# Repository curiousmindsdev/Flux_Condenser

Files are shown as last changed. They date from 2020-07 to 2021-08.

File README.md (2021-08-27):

# Flux Condenser Rev.3

### What is it?

A tiny (35mm x 25mm) PCB badge featuring 24 LEDs that animate to create the “fluxxing” effect. It’s 100% decorative, it doesn’t actually let you travel through time when worn around the neck.

It is controlled by a Microchip ATtiny816 microcontroller. Thankfully this board has a much lower power requirement than the silkscreen indicates on the back, and skips along, sipping power from the single CR2032/LIR2032 coin cell battery (instead of plutonium or a lightning strike), slipped into the rear mounted coin cell holder.

https://user-images.githubusercontent.com/56890227/131141057-b0eb6197-e710-4d84-89a1-9ab057af56d6.mov

https://user-images.githubusercontent.com/56890227/131141300-c1670cdc-f619-4a5a-8890-5401563677f6.mov

### What is changed from Rev.2 to Rev.3?

Thanks to Microchip’s latest ATtiny816 microcontroller now I can dim the LEDs with 8 individual PWM pins. Users can now change the animation type, animation speed, and LED brightness. There are 2 animation types (multi beam and single beam), 2 animation speeds (slow and fast), 4 LED brightness levels (100%, 75%, 50% and 25%).  Power consumption is drastically lowered. At full brightness it draws 2.3mA and at 25% brightness it draws 1.1mA of current from the battery. Also front of the Flux Condenser is now much cleaner. Most of the via drill holes are gone.

### How long will the battery last?

CR2032 (Non-Rechargeable) with average of 210mAh battery capacity.
-	100% LED Brightness :   91 Hours
-	25% LED Brightness	 :   190 Hours

LIR2032 (Rechargeable) with average of 40mAh battery capacity.
-	100% LED Brightness :   17 Hours
-	25% LED Brightness	 :   36 Hours

### Configuration 

To set your desired animation, speed and LED brightness, you have to start flux condenser with configuration interface. In order to do that, you have to turn off your flux condenser. While holding the “Start” button on the back turn the flux condenser on. Now you should see configuration interface. Some of the LEDs should be on and some off according to your configuration. LEDs on each row of all columns, starting from outer to inner are paralleled.  
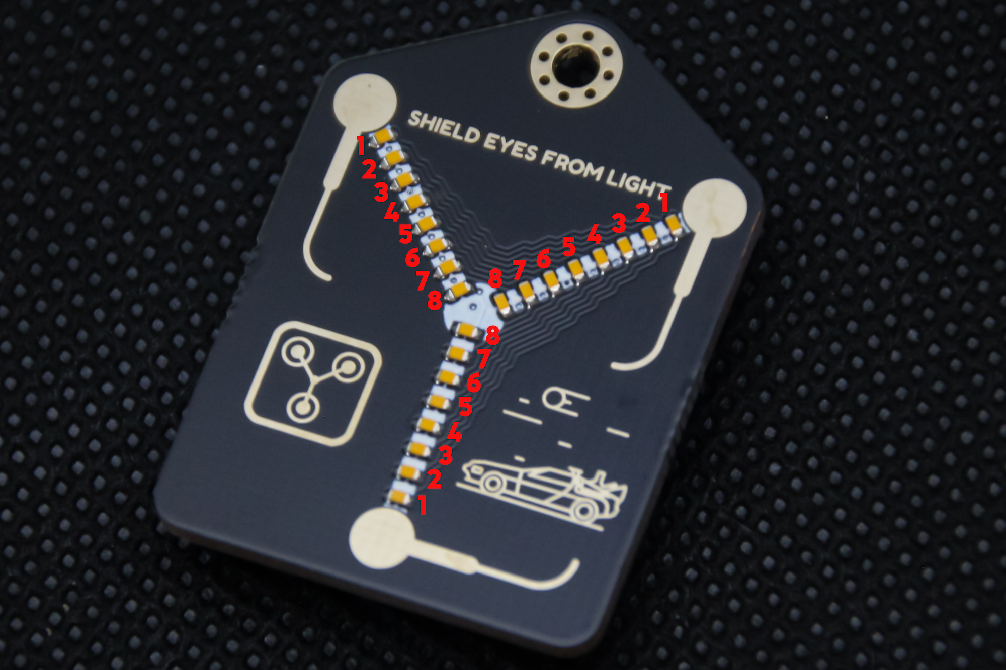
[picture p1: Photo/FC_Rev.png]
LED Numbers

Each LED number from photo shown above represents different setting.

- LED1 : Single Beam Animation
- LED2 : Multi Beam Animation
- LED3 : Slow Animation Speed
- LED4 : Fast Animation Speed
- LED5 : 100% LED Brightness
- LED6 : 75% LED Brightness
- LED7 : 50% LED Brightness
- LED8 : 25% LED Brightness

To choose your preference just hold the start button. All the LEDs should turn off and after a second starting from LED1 each individual LED gets lit. Hold the start until the LED that represents your preferred setting is lit, then release the button. Now your new configuration is set. To see it in more detail check out the video below.

https://www.youtube.com/watch?v=2X2gqoI-mSA

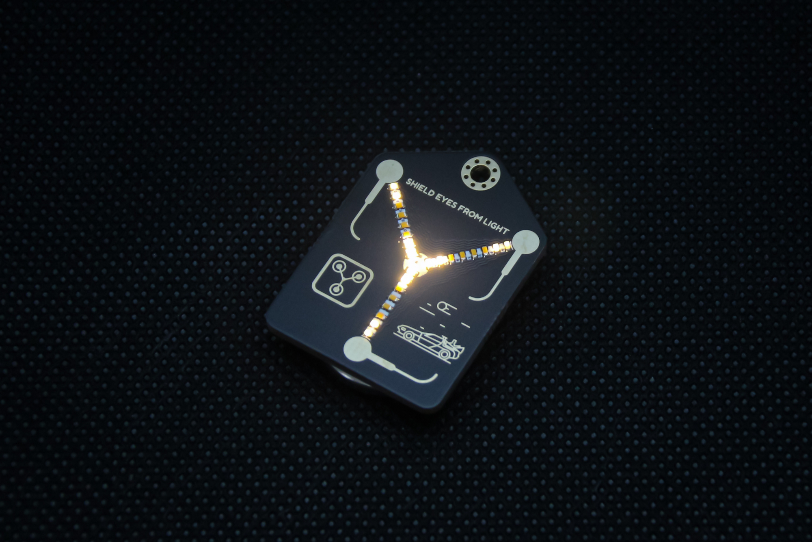
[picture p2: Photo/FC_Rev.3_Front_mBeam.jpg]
Multi Beam

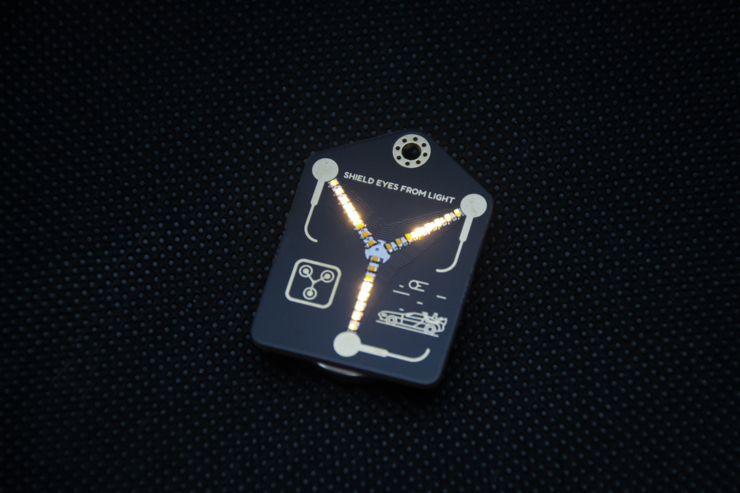
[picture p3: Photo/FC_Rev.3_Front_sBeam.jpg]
Single Beam

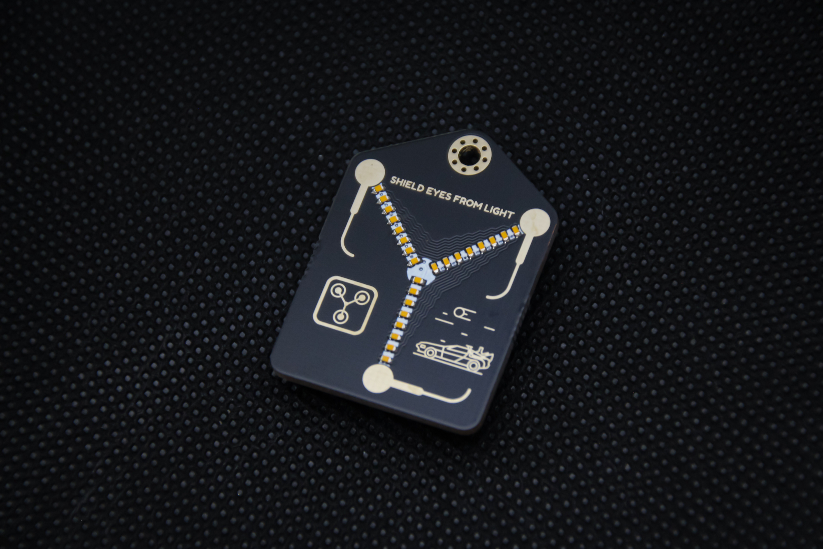
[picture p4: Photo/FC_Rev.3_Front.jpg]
Front

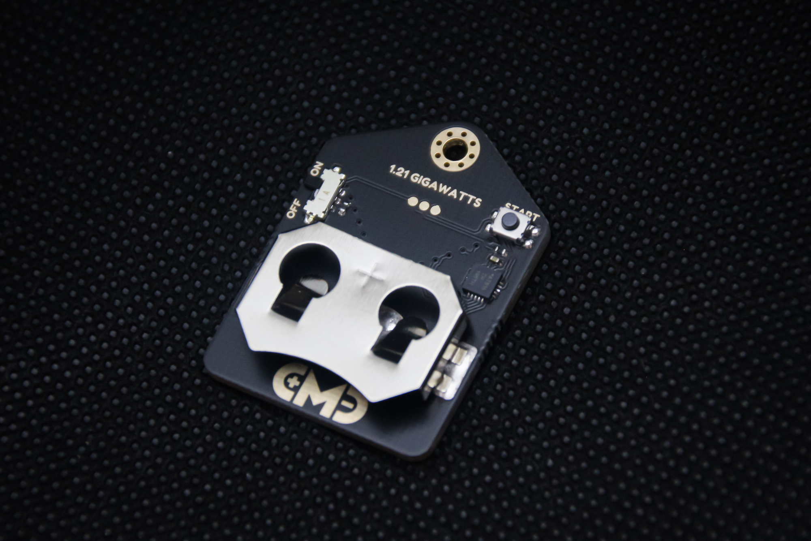
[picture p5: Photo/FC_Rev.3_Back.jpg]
Back






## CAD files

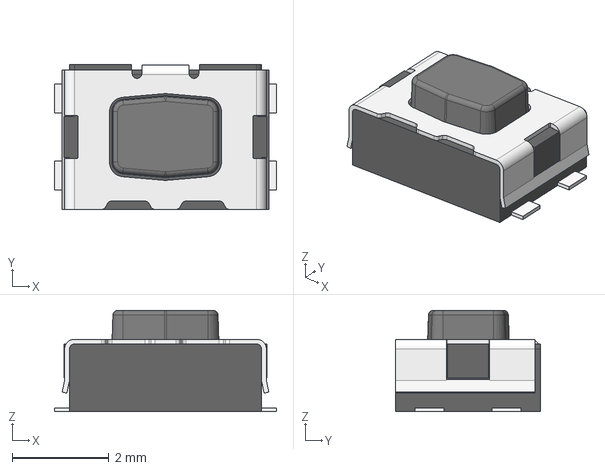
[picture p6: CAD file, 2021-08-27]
3D/Switch-CK-KMR2.step
4.60 x 3.00 x 2.10 mm

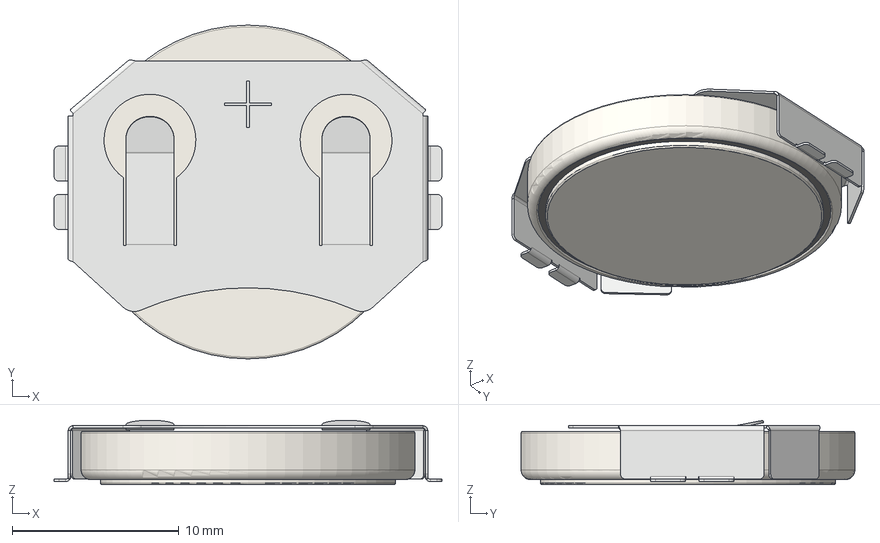
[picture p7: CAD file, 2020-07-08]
3D/CR2032 Metal Holder (with battery).step
23.2 x 20.0 x 3.86 mm
cr2032 smd holder
CR2032 battery v1

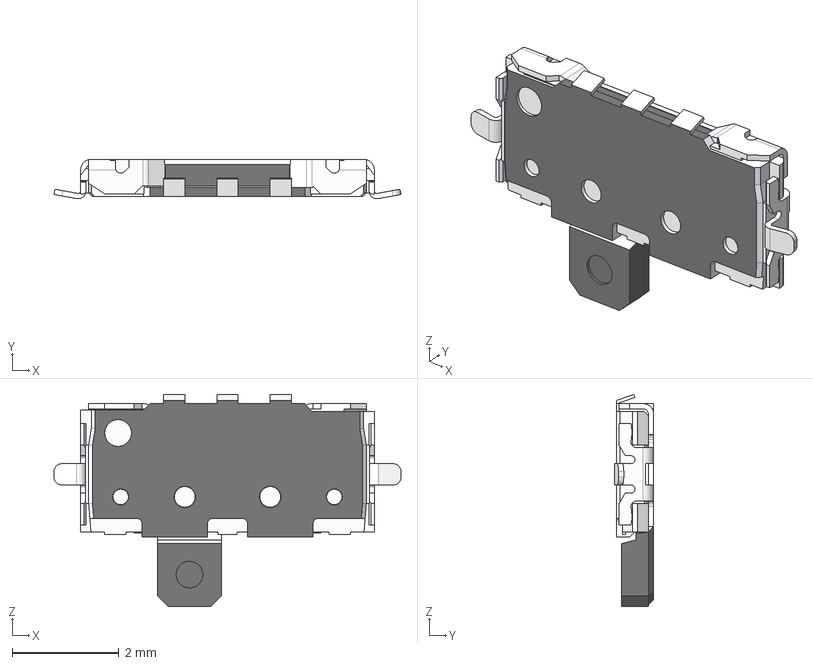
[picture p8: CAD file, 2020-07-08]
3D/Toggle Switch SSAJ120100.STEP
6.50 x 0.74 x 3.98 mm

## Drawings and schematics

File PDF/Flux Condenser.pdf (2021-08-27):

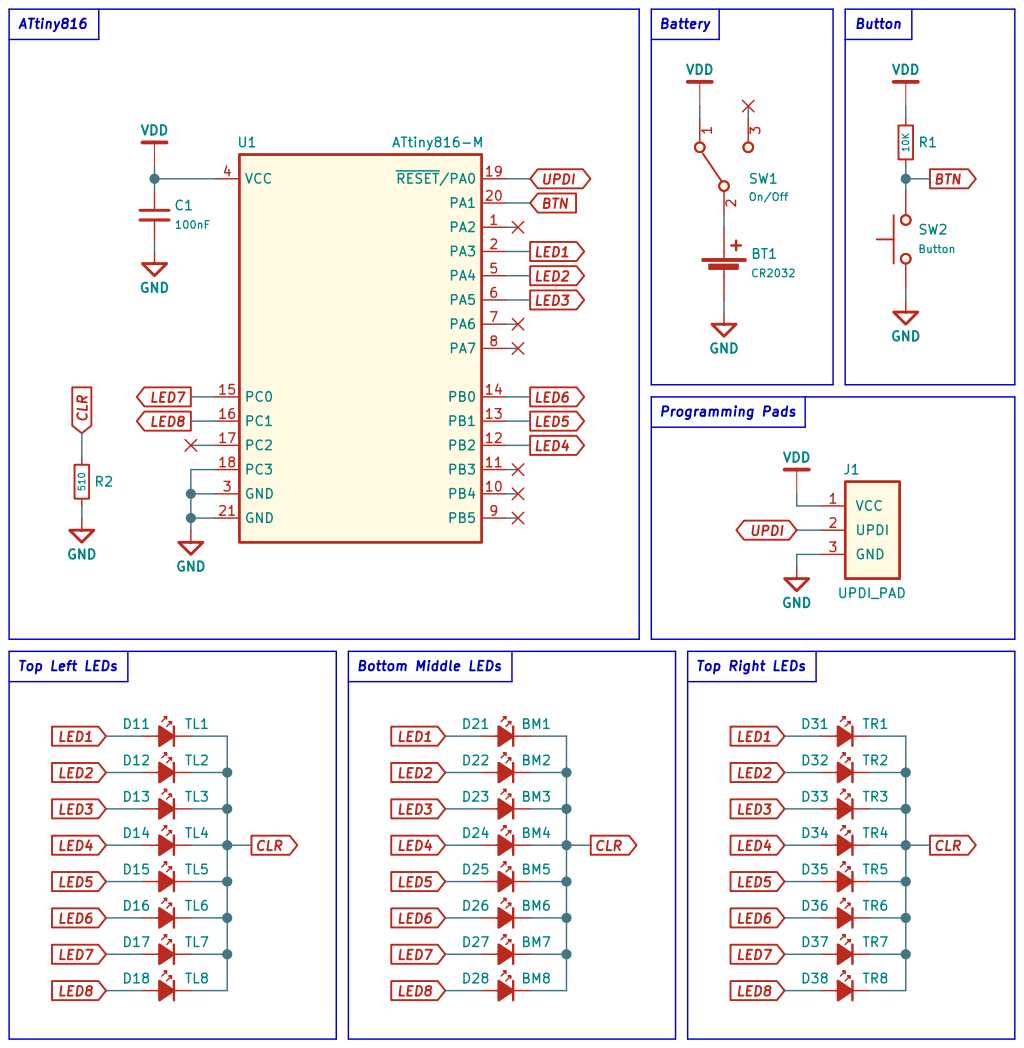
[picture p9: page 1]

Curious Minds Development | Hojadurdy Durdygylyjov

Mini version of Flux Capacitor from Back to the Future

License: CC Attribution-ShareAlike 4.0 International Sheet: 1/1

File: Flux Condenser.kicad_sch

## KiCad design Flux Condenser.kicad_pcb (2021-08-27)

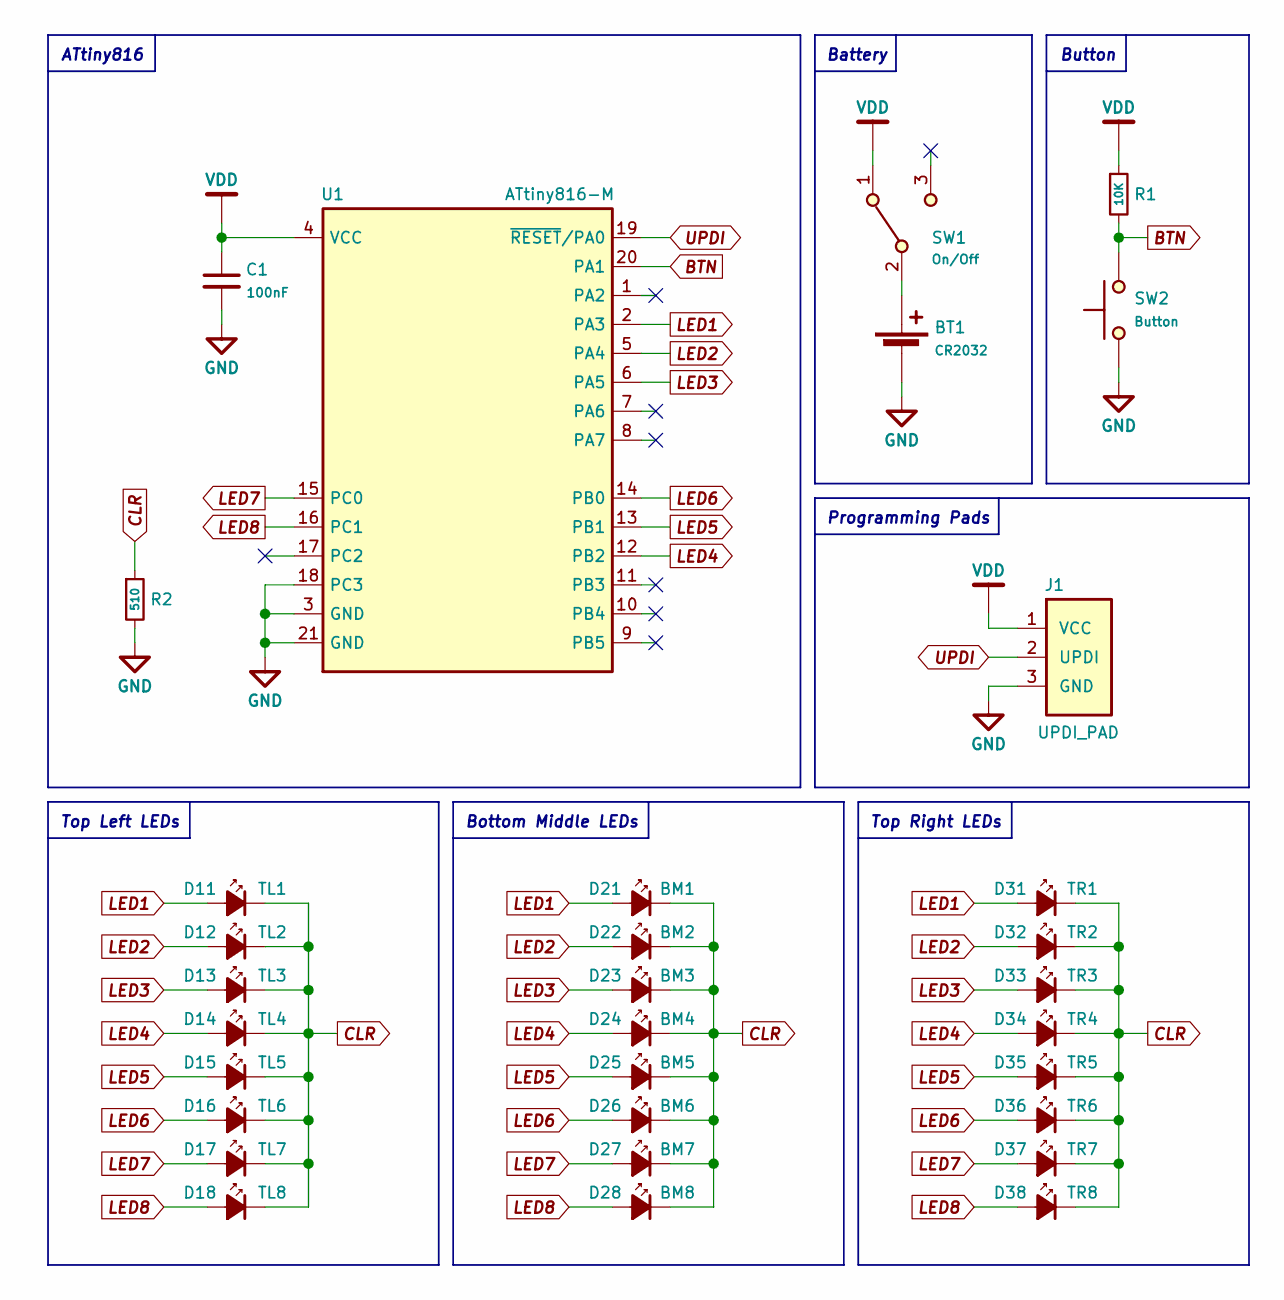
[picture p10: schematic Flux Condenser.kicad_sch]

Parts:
BT1: CR2032; CR2032_Metal_Battery_Holder
C1: 100nF; C_0402_1005Metric
D11: TL1; LED_0402_1005Metric
D12: TL2; LED_0402_1005Metric
D13: TL3; LED_0402_1005Metric
D14: TL4; LED_0402_1005Metric
D15: TL5; LED_0402_1005Metric
D16: TL6; LED_0402_1005Metric
D17: TL7; LED_0402_1005Metric
D18: TL8; LED_0402_1005Metric
D21: BM1; LED_0402_1005Metric
D22: BM2; LED_0402_1005Metric
D23: BM3; LED_0402_1005Metric
D24: BM4; LED_0402_1005Metric
D25: BM5; LED_0402_1005Metric
D26: BM6; LED_0402_1005Metric
D27: BM7; LED_0402_1005Metric
D28: BM8; LED_0402_1005Metric
D31: TR1; LED_0402_1005Metric
D32: TR2; LED_0402_1005Metric
D33: TR3; LED_0402_1005Metric
D34: TR4; LED_0402_1005Metric
D35: TR5; LED_0402_1005Metric
D36: TR6; LED_0402_1005Metric
D37: TR7; LED_0402_1005Metric
D38: TR8; LED_0402_1005Metric
J1: UPDI_PAD; PogoPad_1x03_P1.27mm
R1: 10K; R_0402_1005Metric
R2: 510; R_0402_1005Metric
SW1: On/Off; SSAJ120100
SW2: Button; SW_Push_KH
U1: ATtiny816-M; VQFN-20-1EP_3x3mm_P0.4mm_EP1.7x1.7mm

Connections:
BTN: R1.2, SW2.2, U1.20 (PA1)
CLR: D11.1 (K), D12.1 (K), D13.1 (K), D14.1 (K), D15.1 (K), D16.1 (K), D17.1 (K), D18.1 (K), D21.1 (K), D22.1 (K), D23.1 (K), D24.1 (K), D25.1 (K), D26.1 (K), D27.1 (K), D28.1 (K), D31.1 (K), D32.1 (K), D33.1 (K), D34.1 (K), D35.1 (K), D36.1 (K), D37.1 (K), D38.1 (K), R2.1
GND: BT1.2 (-), C1.2, J1.3 (GND), R2.2, SW2.1, U1.3 (GND), U1.18 (PC3), U1.21 (GND)
LED1: D11.2 (A), D21.2 (A), D31.2 (A), U1.2 (PA3)
LED2: D12.2 (A), D22.2 (A), D32.2 (A), U1.5 (PA4)
LED3: D13.2 (A), D23.2 (A), D33.2 (A), U1.6 (PA5)
LED4: D14.2 (A), D24.2 (A), D34.2 (A), U1.12 (PB2)
LED5: D15.2 (A), D25.2 (A), D35.2 (A), U1.13 (PB1)
LED6: D16.2 (A), D26.2 (A), D36.2 (A), U1.14 (PB0)
LED7: D17.2 (A), D27.2 (A), D37.2 (A), U1.15 (PC0)
LED8: D18.2 (A), D28.2 (A), D38.2 (A), U1.16 (PC1)
unnamed: BT1.1 (+), SW1.2 (B)
UPDI: J1.2 (UPDI), U1.19 (~RESET~/PA0)
VDD: C1.1, J1.1 (VCC), R1.1, SW1.1 (A), U1.4 (VCC)

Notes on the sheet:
ATtiny816
Top Left LEDs
Bottom Middle LEDs
Battery
Programming Pads
Top Right LEDs
Button

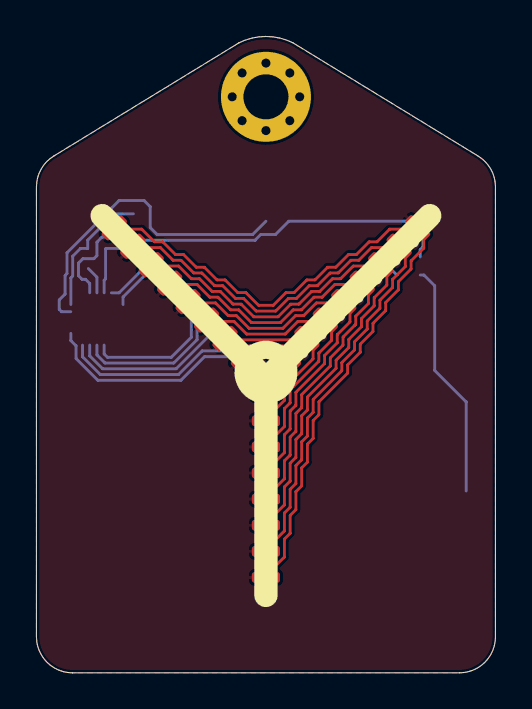
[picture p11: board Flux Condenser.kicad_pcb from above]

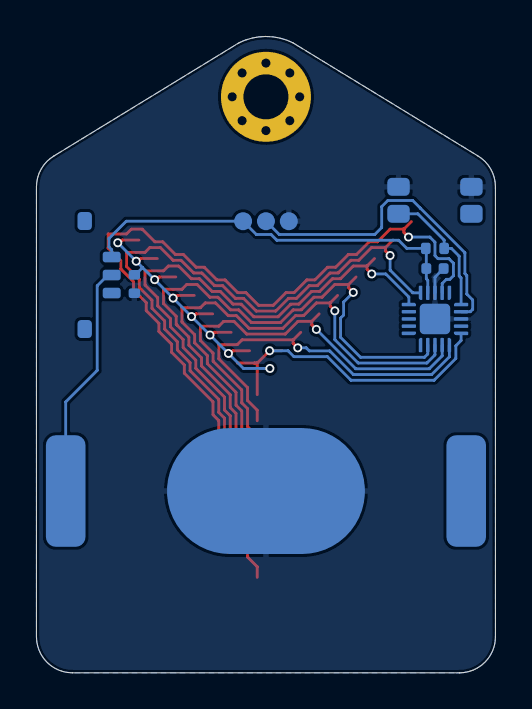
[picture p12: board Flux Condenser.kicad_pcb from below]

Board: 2 copper layers, 25.5 x 35.4 mm, 37 parts (12 on the bottom side), 14 nets.

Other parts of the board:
svg2mod, svg2mod#2, svg2mod#3, svg2mod#4, svg2mod#5: G***; svg2mod

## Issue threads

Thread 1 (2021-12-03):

Adding external wiring

mahtDFR, 2021-12-03:
Hello there, bought one of these from your Tindie.

I'd like to use external wires to power this. I take it I can solder some to the test points, but I'm not sure which is which. I can see there's a schematic but my knowledge of these is rusty.

Is there a diagram that shows the connections? And which voltage should it use? 3V?

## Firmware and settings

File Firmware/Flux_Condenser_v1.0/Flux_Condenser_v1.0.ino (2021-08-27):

#include <EEPROM.h>

const int led1 = 16;
const int led2 = 0;
const int led3 = 1;
const int led4 = 7;
const int led5 = 8;
const int led6 = 9;
const int led7 = 10;
const int led8 = 11;
const int button = 14;

//---BUTTON HOLD TIME PRESETS---//

//Counter Value
float pressLength_ms = 0;

//Animation Type
int singleBeam = 1000;
int multiBeam = 2000;

//Animation Speed
int slow = 3000;
int fast = 4000;

//LED Brightness
int led100 = 5000;
int led75 = 6000;
int led50 = 7000;
int led25 = 8000;

//------------------------------//

int buttonState = 1;

byte startupStateVal;
byte animationType;
byte animationSpeed;
byte ledBrightness;
byte delayVal;
float brightnessScaleVal;

void setup() {               
    pinMode(led1, OUTPUT); 
    pinMode(led2, OUTPUT);
    pinMode(led3, OUTPUT);
    pinMode(led4, OUTPUT);
    pinMode(led5, OUTPUT);
    pinMode(led6, OUTPUT);
    pinMode(led7, OUTPUT);
    pinMode(led8, OUTPUT); 
    pinMode(button, INPUT);   

    byte startupState = digitalRead(button);
    EEPROM.write(1, startupState);
   
//  EEPROM.write(3, 0);     // Values (0,1)             // Animation Type
//  EEPROM.write(5, 50);    // Values (75,50)           // Animation Speed
//  EEPROM.write(7, 255);   // Values (255,191,127,63)  // LED Brightness

}

void loop() {
    startupStateVal = EEPROM.read(1);
    animationType = EEPROM.read(3);
    animationSpeed = EEPROM.read(5);
    ledBrightness = EEPROM.read(7);
    
    switch(startupStateVal) {
        case 0:
            showConfig();
            buttonHoldTimer();
            setConfig();
        break;
        
        case 1:
            buttonState = digitalRead(button);
            if(buttonState == 0){
                if(animationType == 0){
                    multiBeamAnimationFlash();
                }
                else if(animationType == 1){
                    singleBeamAnimationFlash();
                } 
            }
            else if(buttonState == 1){
                if(animationType == 0){
                    multiBeamAnimation();
                }
                else if(animationType == 1){
                    singleBeamAnimation();
                } 
            } 
        break;
    }
}

void showConfig(){
    while (digitalRead(button) == HIGH ){ 
        if(animationType == 0){
            analogWrite(led1, 0);
            analogWrite(led2, ledBrightness);
        }
        else if(animationType == 1){
            analogWrite(led1, ledBrightness);
            analogWrite(led2, 0);
        }

        if(animationSpeed == 50){
            analogWrite(led3, 0);
            analogWrite(led4, ledBrightness);
        }
        else if(animationSpeed == 75){
            analogWrite(led3, ledBrightness);
            analogWrite(led4, 0);
        }
        
        if(ledBrightness == 63){
            analogWrite(led5, 0);
            analogWrite(led6, 0);
            analogWrite(led7, 0);
            analogWrite(led8, ledBrightness);
        }
        else if(ledBrightness == 127){
            analogWrite(led5, 0);
            analogWrite(led6, 0);
            analogWrite(led7, ledBrightness);
            analogWrite(led8, ledBrightness);
        }
        else if(ledBrightness == 191){
            analogWrite(led5, 0);
            analogWrite(led6, ledBrightness);
            analogWrite(led7, ledBrightness);
            analogWrite(led8, ledBrightness);         
        }
        else if(ledBrightness == 255){
            analogWrite(led5, ledBrightness);
            analogWrite(led6, ledBrightness);
            analogWrite(led7, ledBrightness);
            analogWrite(led8, ledBrightness);
        }    
    }            
}

void buttonHoldTimer(){
    analogWrite(led1, 0);
    analogWrite(led2, 0);
    analogWrite(led3, 0);
    analogWrite(led4, 0);
    analogWrite(led5, 0);
    analogWrite(led6, 0);
    analogWrite(led7, 0);
    analogWrite(led8, 0);
    
    while (digitalRead(button) == LOW ){ 
        delay(50);
        pressLength_ms = pressLength_ms + 50; 
        
        if(pressLength_ms >= led25){
            analogWrite(led1, 0);
            analogWrite(led2, 0);
            analogWrite(led3, 0);
            analogWrite(led4, 0);
            analogWrite(led5, 0);
            analogWrite(led6, 0);
            analogWrite(led7, 0);
            analogWrite(led8, ledBrightness);  
        } 
        else if(pressLength_ms >= led50){ 
            analogWrite(led1, 0);
            analogWrite(led2, 0);
            analogWrite(led3, 0);
            analogWrite(led4, 0);
            analogWrite(led5, 0);
            analogWrite(led6, 0);
            analogWrite(led7, ledBrightness);
            analogWrite(led8, 0);  
        }
        else if(pressLength_ms >= led75){
            analogWrite(led1, 0);
            analogWrite(led2, 0);
            analogWrite(led3, 0);
            analogWrite(led4, 0);
            analogWrite(led5, 0);
            analogWrite(led6, ledBrightness);
            analogWrite(led7, 0);
            analogWrite(led8, 0);  
        }
        else if(pressLength_ms >= led100){
            analogWrite(led1, 0);
            analogWrite(led2, 0);
            analogWrite(led3, 0);
            analogWrite(led4, 0);
            analogWrite(led5, ledBrightness);
            analogWrite(led6, 0);
            analogWrite(led7, 0);
            analogWrite(led8, 0);  
        }
        else if(pressLength_ms >= fast){ 
            analogWrite(led1, 0);
            analogWrite(led2, 0);
            analogWrite(led3, 0);
            analogWrite(led4, ledBrightness);
            analogWrite(led5, 0);
            analogWrite(led6, 0);
            analogWrite(led7, 0);
            analogWrite(led8, 0);  
        }
        else if(pressLength_ms >= slow){ 
            analogWrite(led1, 0);
            analogWrite(led2, 0);
            analogWrite(led3, ledBrightness);
            analogWrite(led4, 0);
            analogWrite(led5, 0);
            analogWrite(led6, 0);
            analogWrite(led7, 0);
            analogWrite(led8, 0);  
        }
        else if(pressLength_ms >= multiBeam){ 
            analogWrite(led1, 0);
            analogWrite(led2, ledBrightness);
            analogWrite(led3, 0);
            analogWrite(led4, 0);
            analogWrite(led5, 0);
            analogWrite(led6, 0);
            analogWrite(led7, 0);
            analogWrite(led8, 0);  
        }
        else if(pressLength_ms >= singleBeam){  
            analogWrite(led1, ledBrightness);
            analogWrite(led2, 0);
            analogWrite(led3, 0);
            analogWrite(led4, 0);
            analogWrite(led5, 0);
            analogWrite(led6, 0);
            analogWrite(led7, 0);
            analogWrite(led8, 0);  
        }      
    }
}

void setConfig(){
    if(pressLength_ms >= led25){
        EEPROM.write(7, 63);  
    } 
    else if(pressLength_ms >= led50){ 
        EEPROM.write(7, 127);  
    }
    else if(pressLength_ms >= led75){
        EEPROM.write(7, 191);  
    }
    else if(pressLength_ms >= led100){
        EEPROM.write(7, 255);  
    }
    else if(pressLength_ms >= fast){ 
        EEPROM.write(5, 50);  
    }
    else if(pressLength_ms >= slow){ 
        EEPROM.write(5, 75);  
    }
    else if(pressLength_ms >= multiBeam){ 
        EEPROM.write(3, 0);  
    }
    else if(pressLength_ms >= singleBeam){  
        EEPROM.write(3, 1);  
    }
    pressLength_ms = 0;
}

void singleBeamAnimation(){
    float brightnessScaleVal = ledBrightness/255.00;
    analogWrite(led1, 10*brightnessScaleVal);
    delay(animationSpeed-10); 
    analogWrite(led2, 30*brightnessScaleVal);
    delay(animationSpeed-10); 
    analogWrite(led3, 60*brightnessScaleVal);
    delay(animationSpeed-10);
    analogWrite(led4, 100*brightnessScaleVal);
    delay(animationSpeed);
    analogWrite(led5, 150*brightnessScaleVal);
    delay(animationSpeed-10);
    analogWrite(led1, 0);
    analogWrite(led2, 10*brightnessScaleVal);
    analogWrite(led3, 30*brightnessScaleVal);
    analogWrite(led4, 60*brightnessScaleVal);
    analogWrite(led5, 100*brightnessScaleVal);
    analogWrite(led6, 180*brightnessScaleVal);
    delay(animationSpeed-10);
    analogWrite(led2, 0);
    analogWrite(led3, 10*brightnessScaleVal);
    analogWrite(led4, 30*brightnessScaleVal);
    analogWrite(led5, 70*brightnessScaleVal);
    analogWrite(led6, 130*brightnessScaleVal);
    analogWrite(led7, 200*brightnessScaleVal);
    delay(animationSpeed-10);
    analogWrite(led3, 0);
    analogWrite(led4, 20*brightnessScaleVal);
    analogWrite(led5, 80*brightnessScaleVal);
    analogWrite(led6, 150*brightnessScaleVal);
    analogWrite(led7, 180*brightnessScaleVal);
    analogWrite(led8, 255*brightnessScaleVal);
    delay(animationSpeed-10);
    analogWrite(led4, 0);
    delay(animationSpeed-10);
    analogWrite(led5, 0);
    delay(animationSpeed-10);
    analogWrite(led6, 0);
    delay(animationSpeed-10);
    analogWrite(led7, 0);
    delay(animationSpeed-10);
    analogWrite(led8, 0);
}

void singleBeamAnimationFlash(){
    float brightnessScaleVal = ledBrightness/255.00;
    for(int del=40;del>0;del--){
        analogWrite(led1, 10*brightnessScaleVal);
        delay(del); 
        analogWrite(led2, 30*brightnessScaleVal);
        delay(del); 
        analogWrite(led3, 60*brightnessScaleVal);
        delay(del);
        analogWrite(led4, 100*brightnessScaleVal);
        delay(del);
        analogWrite(led5, 150*brightnessScaleVal);
        delay(del);
        analogWrite(led1, 0);
        analogWrite(led2, 10*brightnessScaleVal);
        analogWrite(led3, 30*brightnessScaleVal);
        analogWrite(led4, 60*brightnessScaleVal);
        analogWrite(led5, 100*brightnessScaleVal);
        analogWrite(led6, 180*brightnessScaleVal);
        delay(del);
        analogWrite(led2, 0);
        analogWrite(led3, 10*brightnessScaleVal);
        analogWrite(led4, 30*brightnessScaleVal);
        analogWrite(led5, 70*brightnessScaleVal);
        analogWrite(led6, 130*brightnessScaleVal);
        analogWrite(led7, 200*brightnessScaleVal);
        delay(del);
        analogWrite(led3, 0);
        analogWrite(led4, 20*brightnessScaleVal);
        analogWrite(led5, 80*brightnessScaleVal);
        analogWrite(led6, 150*brightnessScaleVal);
        analogWrite(led7, 180*brightnessScaleVal);
        analogWrite(led8, 255*brightnessScaleVal);
        delay(del);
        analogWrite(led4, 0);
        delay(del);
        analogWrite(led5, 0);
        delay(del);
        analogWrite(led6, 0);
        delay(del);
        analogWrite(led7, 0);
        delay(del);
        analogWrite(led8, 0);
    }

    digitalWrite(led1, LOW);
    digitalWrite(led2, LOW);
    digitalWrite(led3, LOW);
    digitalWrite(led4, LOW);
    digitalWrite(led5, LOW);
    digitalWrite(led6, LOW);
    digitalWrite(led7, LOW);
    digitalWrite(led8, LOW);
    delay(60);
    digitalWrite(led1, HIGH);
    digitalWrite(led2, HIGH);
    digitalWrite(led3, HIGH);
    digitalWrite(led4, HIGH);
    digitalWrite(led5, HIGH);
    digitalWrite(led6, HIGH);
    digitalWrite(led7, HIGH);
    digitalWrite(led8, HIGH);
    delay(60);
    digitalWrite(led1, LOW);
    digitalWrite(led2, LOW);
    digitalWrite(led3, LOW);
    digitalWrite(led4, LOW);
    digitalWrite(led5, LOW);
    digitalWrite(led6, LOW);
    digitalWrite(led7, LOW);
    digitalWrite(led8, LOW);
    delay(60);
    digitalWrite(led1, HIGH);
    digitalWrite(led2, HIGH);
    digitalWrite(led3, HIGH);
    digitalWrite(led4, HIGH);
    digitalWrite(led5, HIGH);
    digitalWrite(led6, HIGH);
    digitalWrite(led7, HIGH);
    digitalWrite(led8, HIGH);
    delay(60);
    digitalWrite(led1, LOW);
    digitalWrite(led2, LOW);
    digitalWrite(led3, LOW);
    digitalWrite(led4, LOW);
    digitalWrite(led5, LOW);
    digitalWrite(led6, LOW);
    digitalWrite(led7, LOW);
    digitalWrite(led8, LOW);
    delay(60);
    digitalWrite(led1, HIGH);
    digitalWrite(led2, HIGH);
    digitalWrite(led3, HIGH);
    digitalWrite(led4, HIGH);
    digitalWrite(led5, HIGH);
    digitalWrite(led6, HIGH);
    digitalWrite(led7, HIGH);
    digitalWrite(led8, HIGH);
    delay(60);
    digitalWrite(led1, LOW);
    digitalWrite(led2, LOW);
    digitalWrite(led3, LOW);
    digitalWrite(led4, LOW);
    digitalWrite(led5, LOW);
    digitalWrite(led6, LOW);
    digitalWrite(led7, LOW);
    digitalWrite(led8, LOW);
}

void multiBeamAnimation(){
    float brightnessScaleVal = ledBrightness/255.00;
    analogWrite(led1, 31*brightnessScaleVal);
    analogWrite(led6, 191*brightnessScaleVal);
    analogWrite(led7, 223*brightnessScaleVal);
    delay(animationSpeed); 
    analogWrite(led1, 31*brightnessScaleVal);
    analogWrite(led2, 63*brightnessScaleVal);
    analogWrite(led7, 223*brightnessScaleVal);
    analogWrite(led8, 255*brightnessScaleVal);
    analogWrite(led6, 0);
    delay(animationSpeed);
    analogWrite(led2, 63*brightnessScaleVal);
    analogWrite(led3, 95*brightnessScaleVal);
    analogWrite(led8, 255*brightnessScaleVal);
    analogWrite(led1, 0);
    analogWrite(led7, 0);
    delay(animationSpeed);
    analogWrite(led3, 95*brightnessScaleVal);
    analogWrite(led4, 127*brightnessScaleVal);
    analogWrite(led2, 0);
    analogWrite(led8, 0);
    delay(animationSpeed);
    analogWrite(led4, 127*brightnessScaleVal);
    analogWrite(led5, 159*brightnessScaleVal);
    analogWrite(led3, 0);
    delay(animationSpeed);
    analogWrite(led5, 159*brightnessScaleVal);
    analogWrite(led6, 191*brightnessScaleVal);
    analogWrite(led4, 0);
    delay(animationSpeed);
    analogWrite(led5, 0);
}

void multiBeamAnimationFlash(){
    float brightnessScaleVal = ledBrightness/255.00;
    for(int del=50;del>0;del--){
        analogWrite(led1, 32*brightnessScaleVal);
        analogWrite(led6, 192*brightnessScaleVal);
        analogWrite(led7, 224*brightnessScaleVal);
        delay(del); 
        analogWrite(led1, 32*brightnessScaleVal);
        analogWrite(led2, 64*brightnessScaleVal);
        analogWrite(led7, 224*brightnessScaleVal);
        analogWrite(led8, 254*brightnessScaleVal);
        analogWrite(led6, 0);
        delay(del);
        analogWrite(led2, 64*brightnessScaleVal);
        analogWrite(led3, 96*brightnessScaleVal);
        analogWrite(led8, 254*brightnessScaleVal);
        analogWrite(led1, 0);
        analogWrite(led7, 0);
        delay(del);
        analogWrite(led3, 96*brightnessScaleVal);
        analogWrite(led4, 128*brightnessScaleVal);
        analogWrite(led2, 0);
        analogWrite(led8, 0);
        delay(del);
        analogWrite(led4, 128*brightnessScaleVal);
        analogWrite(led5, 160*brightnessScaleVal);
        analogWrite(led3, 0);
        delay(del);
        analogWrite(led5, 160*brightnessScaleVal);
        analogWrite(led6, 192*brightnessScaleVal);
        analogWrite(led4, 0);
        delay(del);
        analogWrite(led5, 0);
    }

    digitalWrite(led1, LOW);
    digitalWrite(led2, LOW);
    digitalWrite(led3, LOW);
    digitalWrite(led4, LOW);
    digitalWrite(led5, LOW);
    digitalWrite(led6, LOW);
    digitalWrite(led7, LOW);
    digitalWrite(led8, LOW);
    delay(60);
    digitalWrite(led1, HIGH);
    digitalWrite(led2, HIGH);
    digitalWrite(led3, HIGH);
    digitalWrite(led4, HIGH);
    digitalWrite(led5, HIGH);
    digitalWrite(led6, HIGH);
    digitalWrite(led7, HIGH);
    digitalWrite(led8, HIGH);
    delay(60);
    digitalWrite(led1, LOW);
    digitalWrite(led2, LOW);
    digitalWrite(led3, LOW);
    digitalWrite(led4, LOW);
    digitalWrite(led5, LOW);
    digitalWrite(led6, LOW);
    digitalWrite(led7, LOW);
    digitalWrite(led8, LOW);
    delay(60);
    digitalWrite(led1, HIGH);
    digitalWrite(led2, HIGH);
    digitalWrite(led3, HIGH);
    digitalWrite(led4, HIGH);
    digitalWrite(led5, HIGH);
    digitalWrite(led6, HIGH);
    digitalWrite(led7, HIGH);
    digitalWrite(led8, HIGH);
    delay(60);
    digitalWrite(led1, LOW);
    digitalWrite(led2, LOW);
    digitalWrite(led3, LOW);
    digitalWrite(led4, LOW);
    digitalWrite(led5, LOW);
    digitalWrite(led6, LOW);
    digitalWrite(led7, LOW);
    digitalWrite(led8, LOW);
    delay(60);
    digitalWrite(led1, HIGH);
    digitalWrite(led2, HIGH);
    digitalWrite(led3, HIGH);
    digitalWrite(led4, HIGH);
    digitalWrite(led5, HIGH);
    digitalWrite(led6, HIGH);
    digitalWrite(led7, HIGH);
    digitalWrite(led8, HIGH);
    delay(60);
    digitalWrite(led1, LOW);
    digitalWrite(led2, LOW);
    digitalWrite(led3, LOW);
    digitalWrite(led4, LOW);
    digitalWrite(led5, LOW);
    digitalWrite(led6, LOW);
    digitalWrite(led7, LOW);
    digitalWrite(led8, LOW);
} 

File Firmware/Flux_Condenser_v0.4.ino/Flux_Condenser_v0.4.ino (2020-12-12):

const int led1 = 0;
const int led2 = 1;
const int led3 = 2;
const int led4 = 3;
const int led5 = 4;
const int led6 = 5;
const int led7 = 6;
const int led8 = 7;
const int button = 10;
int buttonState = 1; 
int lastButtonState = 1;

void setup() {               
  pinMode(led1, OUTPUT); 
  pinMode(led2, OUTPUT);
  pinMode(led3, OUTPUT);
  pinMode(led4, OUTPUT);
  pinMode(led5, OUTPUT);
  pinMode(led6, OUTPUT);
  pinMode(led7, OUTPUT);
  pinMode(led8, OUTPUT); 
  pinMode(button, INPUT);   
}

void loop() {

    buttonState = digitalRead(button);
    switch (buttonState) {
    case 0:
      for(int del=50;del>0;del--)
      {
          digitalWrite(led1, HIGH);
          digitalWrite(led6, HIGH);
          digitalWrite(led7, HIGH);
          delay(del); 
          digitalWrite(led1, HIGH);
          digitalWrite(led2, HIGH);
          digitalWrite(led7, HIGH);
          digitalWrite(led8, HIGH);
          digitalWrite(led6, LOW);
          delay(del);
          digitalWrite(led2, HIGH);
          digitalWrite(led3, HIGH);
          digitalWrite(led8, HIGH);
          digitalWrite(led1, LOW);
          digitalWrite(led7, LOW);
          delay(del);
          digitalWrite(led3, HIGH);
          digitalWrite(led4, HIGH);
          digitalWrite(led2, LOW);
          digitalWrite(led8, LOW);
          delay(del);
          digitalWrite(led4, HIGH);
          digitalWrite(led5, HIGH);
          digitalWrite(led3, LOW);
          delay(del);
          digitalWrite(led5, HIGH);
          digitalWrite(led6, HIGH);
          digitalWrite(led4, LOW);
          delay(del);
          digitalWrite(led5, LOW);
      }
  
      digitalWrite(led1, LOW);
      digitalWrite(led2, LOW);
      digitalWrite(led3, LOW);
      digitalWrite(led4, LOW);
      digitalWrite(led5, LOW);
      digitalWrite(led6, LOW);
      digitalWrite(led7, LOW);
      digitalWrite(led8, LOW);
      delay(60);
      digitalWrite(led1, HIGH);
      digitalWrite(led2, HIGH);
      digitalWrite(led3, HIGH);
      digitalWrite(led4, HIGH);
      digitalWrite(led5, HIGH);
      digitalWrite(led6, HIGH);
      digitalWrite(led7, HIGH);
      digitalWrite(led8, HIGH);
      delay(60);
      digitalWrite(led1, LOW);
      digitalWrite(led2, LOW);
      digitalWrite(led3, LOW);
      digitalWrite(led4, LOW);
      digitalWrite(led5, LOW);
      digitalWrite(led6, LOW);
      digitalWrite(led7, LOW);
      digitalWrite(led8, LOW);
      delay(60);
      digitalWrite(led1, HIGH);
      digitalWrite(led2, HIGH);
      digitalWrite(led3, HIGH);
      digitalWrite(led4, HIGH);
      digitalWrite(led5, HIGH);
      digitalWrite(led6, HIGH);
      digitalWrite(led7, HIGH);
      digitalWrite(led8, HIGH);
      delay(60);
      digitalWrite(led1, LOW);
      digitalWrite(led2, LOW);
      digitalWrite(led3, LOW);
      digitalWrite(led4, LOW);
      digitalWrite(led5, LOW);
      digitalWrite(led6, LOW);
      digitalWrite(led7, LOW);
      digitalWrite(led8, LOW);
      delay(60);
      digitalWrite(led1, HIGH);
      digitalWrite(led2, HIGH);
      digitalWrite(led3, HIGH);
      digitalWrite(led4, HIGH);
      digitalWrite(led5, HIGH);
      digitalWrite(led6, HIGH);
      digitalWrite(led7, HIGH);
      digitalWrite(led8, HIGH);
      delay(60);
      break;
      
      case 1:    
      digitalWrite(led1, HIGH);
      digitalWrite(led6, HIGH);
      digitalWrite(led7, HIGH);
      delay(50); 
      digitalWrite(led1, HIGH);
      digitalWrite(led2, HIGH);
      digitalWrite(led7, HIGH);
      digitalWrite(led8, HIGH);
      digitalWrite(led6, LOW);
      delay(50);
      digitalWrite(led2, HIGH);
      digitalWrite(led3, HIGH);
      digitalWrite(led8, HIGH);
      digitalWrite(led1, LOW);
      digitalWrite(led7, LOW);
      delay(50);
      digitalWrite(led3, HIGH);
      digitalWrite(led4, HIGH);
      digitalWrite(led2, LOW);
      digitalWrite(led8, LOW);
      delay(50);
      digitalWrite(led4, HIGH);
      digitalWrite(led5, HIGH);
      digitalWrite(led3, LOW);
      delay(50);
      digitalWrite(led5, HIGH);
      digitalWrite(led6, HIGH);
      digitalWrite(led4, LOW);
      delay(50);
      digitalWrite(led5, LOW);
      break;
  }
}
